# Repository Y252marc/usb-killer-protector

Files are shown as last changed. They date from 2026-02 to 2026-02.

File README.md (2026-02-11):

# USB killer Protector | 🛡️ USB SHIELD | The 5kV Hard-Isolation Barrier
**Magnetic isolation. Zero physical connection. Total motherboard safety.**





👉 **[Launch Interactive Project Site](https://y252marc.github.io/usb-killer-protector/)**

---

### ⚡ The Problem: The "Spark"
USB Killers don't hack your software; they execute your hardware. By dumping high-voltage DC into your port, they fry your motherboard in milliseconds. Standard protectors are too slow.

### 🔌 The Solution: The "Moat"
I didn't just build a filter; I built a physical gap. Data is teleported across a 4.5mm "moat" using magnetic fields, while power is handled by a floating transformer. If an attacker dumps 200V into the target side, it literally has no physical path to reach your laptop.

---

### 🛠️ Hardware Loadout
* **The Brain**: **ADuM4160** Digital Isolator (Rated for **5,000V** isolation).
* **The Power**: **RFM-0505S** Isolated DC-DC Converter (Floating 5V power).
* **The Guard**: Dual **SMAJ5.0A** TVS Diodes (Clamping transients at the source).
* **The Kill Switch**: **JS202011SCQN** DPDT switch for instant manual data disconnection.

---

### 📐 Engineering Excellence
* **Split Ground Planes**: Two entirely separate copper islands—Clean vs. Dirty.
* **Differential Data Highway**: Matched D+/D- lines with 24Ω termination for zero-drop communication.
* **Pro Layout**: 2-layer FR4 with 2mm rounded edges for a clean, crack-proof finish.

### 📂 Inside the Repo
* **3D Assets**: STEP models for the isolator, transformer, and ports.
* **Production**: Factory-ready Gerber and Drill files.
* **Source**: Full KiCad 9 design project.

---

### 📜 License
This project is licensed under the **MIT License** - see the [LICENSE](LICENSE) file for details.

### ⚠️ Disclaimer
*Testing destructive hardware is dangerous. This shield is for research and educational vibes only. Use it at your own risk.*

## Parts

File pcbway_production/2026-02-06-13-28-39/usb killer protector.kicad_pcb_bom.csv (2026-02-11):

Designator | Quantity | Value | Footprint | Package | MPN | DNP | Mount_Type | Description | MF | Description_1 | Price | SnapEDA_Link | MP | Availability | Check_prices | MFR_NAME | MANUFACTURER_PART_NUMBER | MAXIMUM_PACKAGE_HEIGHT | STANDARD | PARTREV | MANUFACTURER | SNAPEDA_PN | OC_FARNELL | SUPPLIER | OC_NEWARK
C1, C2, C3, C4 | 4 | 100uF | C_0805_2012Metric |  |  |  | smt | SMD 0805 MLCC capacitor, Alternate KiCad Library
C5 | 1 | 10uF | C_1206_3216Metric |  |  |  | smt | SMD 1206 MLCC capacitor, Alternate KiCad Library
D1, D2 | 2 | SMAJ5.0A | D_SMA |  |  |  | smt | SMA Unidirectional TVS diode, 5V, 400W, Alternate KiCAD Library
F1 | 1 | 0ZCJ0050FF2G | RESC3216X125N | 1206 Bel Fuse |  |  | smt |  | Bel Fuse | 1206 SMT PPTC | 0.50 Ih | 8V | None | https://www.snapeda.com/parts/0ZCJ0050FF2G/Bel+Circuit+Protection/view-part/?ref=snap | 0ZCJ0050FF2G | In Stock | https://www.snapeda.com/parts/0ZCJ0050FF2G/Bel+Circuit+Protection/view-part/?ref=eda
J1 | 1 | 480370001 | USB_A_Molex_48037-2200_Horizontal | None |  |  | smt |  | Molex | USB-A (USB TYPE-A) USB 2.0 Plug Connector 4 Position Through Hole, Right Angle | None | https://www.snapeda.com/parts/480370001/Molex/view-part/?ref=snap | 480370001 | In Stock | https://www.snapeda.com/parts/480370001/Molex/view-part/?ref=eda | Molex Connector Corporation | 480370001
J2 | 1 | USB1125-GF-B_REVA | GCT_USB1125-GF-B_REVA | None |  |  | tht |  | Global Connector Technology | USB 2.0 Receptacle, Type A, Through Hole, Horizontal, Top Mount, Without Flange, 6.48mm profile, 4 Pins, Through hole, compact receptacle, 5000 mating cycle, full size | None | https://www.snapeda.com/parts/USB1125-GF-B/Global+Connector+Technology/view-part/?ref=snap | USB1125-GF-B | In Stock | https://www.snapeda.com/parts/USB1125-GF-B/Global+Connector+Technology/view-part/?ref=eda |  |  | 6.63mm | Manufacturer Recommendations | A | GCT
R1, R2, R3, R4 | 4 | 24Ω | R_0805_2012Metric |  |  |  | smt | SMD 0805 Chip Resistor, European Symbol, Alternate KiCad Library
SW1 | 1 | JS202011SCQN | SW_JS202011SCQN | None |  |  | smt |  | C&K | Slide Switch DPDT Surface Mount | None | https://www.snapeda.com/parts/JS202011SCQN/C%2526K/view-part/?ref=snap | JS202011SCQN | In Stock | https://www.snapeda.com/parts/JS202011SCQN/C%2526K/view-part/?ref=eda |  |  | 5.5 mm | Manufacturer Recommendations | 26 May 22 | C&K | JS202011SCQN
U1 | 1 | ADUM4160BRWZ | SOIC127P1032X265-16N | SOIC-16 | ADUM4160BRWZ |  | smt |  | Analog Devices | Full/Low Speed USB Digital Isolator | None | https://www.snapeda.com/parts/ADUM4160BRWZ/Analog+Devices/view-part/?ref=snap | ADUM4160BRWZ | In Stock | https://www.snapeda.com/parts/ADUM4160BRWZ/Analog+Devices/view-part/?ref=eda |  |  |  |  |  |  |  | 1858056 | Analog Devices | 24R8652
U2 | 1 | RFM-0505S | CONV_RFM-0505S | SIP-4 Recom Power |  |  | tht |  | Recom Power | DC-DC Converter, SIP4, 1kV unreg, Single Output, 1W, 5V Out, RFM Series | RECOM Power Inc. RFM-0505S | None | https://www.snapeda.com/parts/RFM-0505S/Recom+Power/view-part/?ref=snap | RFM-0505S | In Stock | https://www.snapeda.com/parts/RFM-0505S/Recom+Power/view-part/?ref=eda |  |  | 10mm | Manufacturer Recommendations | 0 | Recom

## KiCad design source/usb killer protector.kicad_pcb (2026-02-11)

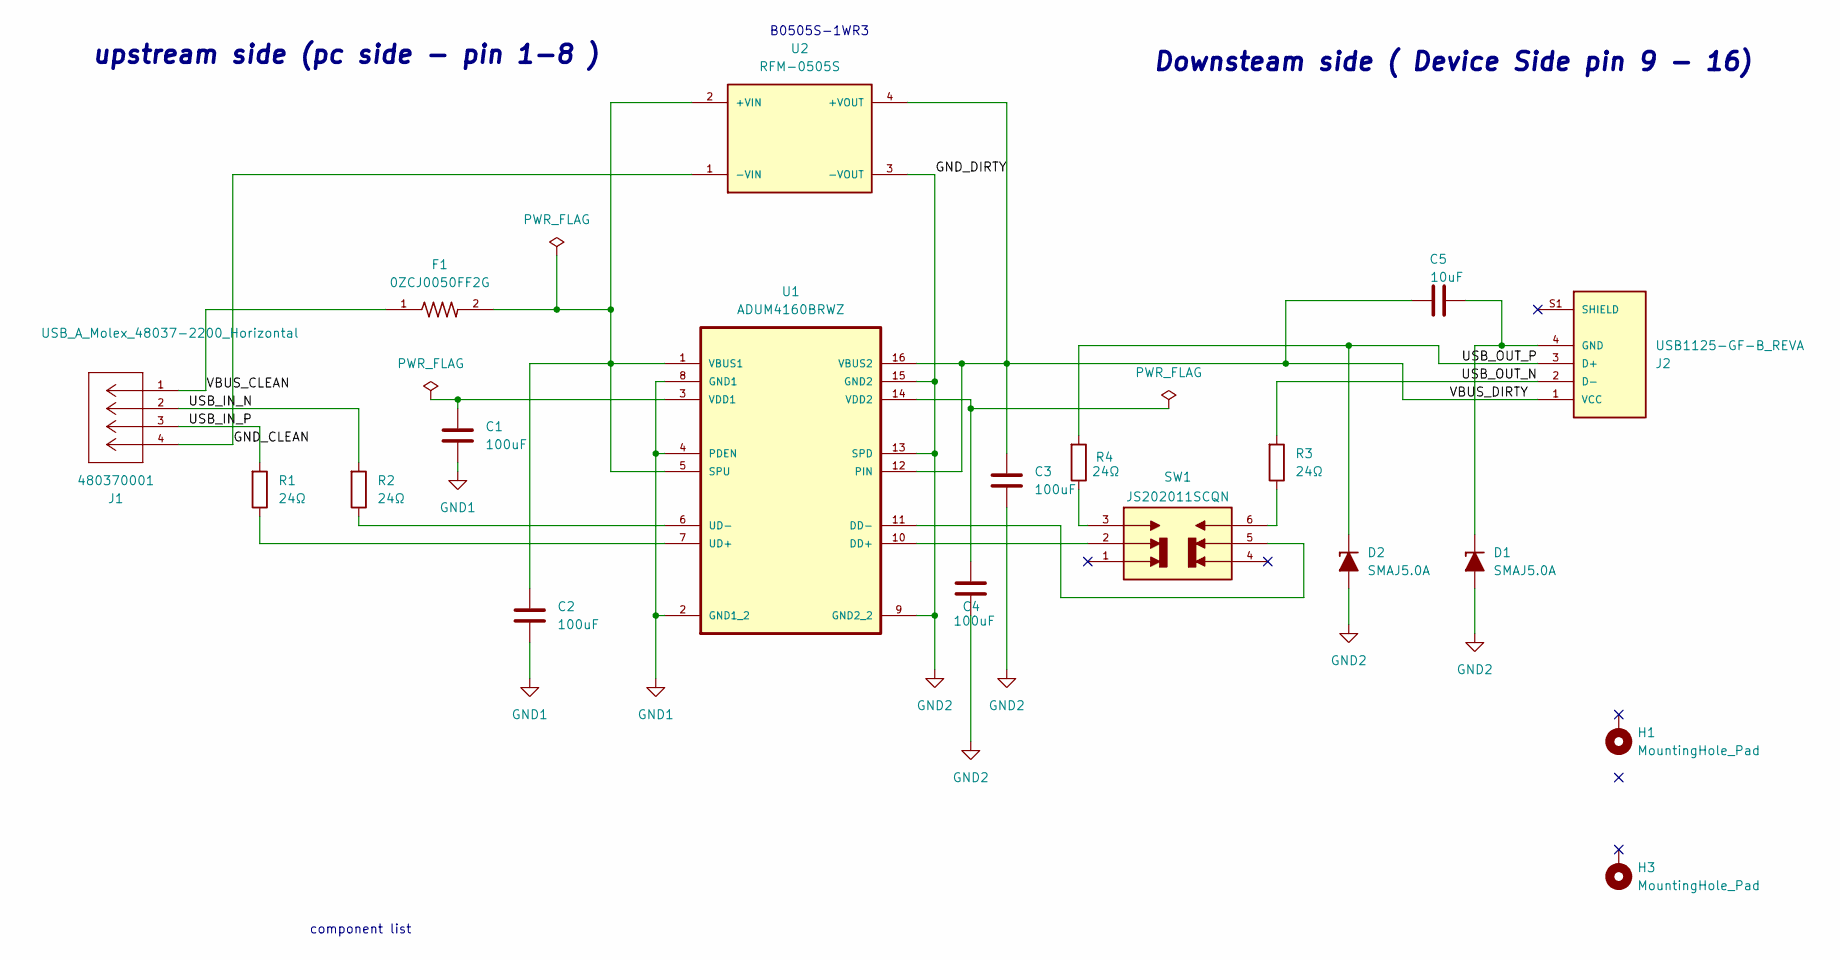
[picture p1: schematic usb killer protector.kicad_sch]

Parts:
C1, C2, C3, C4: 100uF; C_0805_2012Metric
C5: 10uF; C_1206_3216Metric
D1, D2: SMAJ5.0A; D_SMA
F1: 0ZCJ0050FF2G; RESC3216X125N
H1, H3: MountingHole_Pad; MountingHole_3.2mm_M3_Pad_Via
J1: 480370001; USB_A_Molex_48037-2200_Horizontal; MANUFACTURER_PART_NUMBER 480370001
J2: USB1125-GF-B_REVA; GCT_USB1125-GF-B_REVA; PARTREV A
R1, R2, R3, R4: 24Ω; R_0805_2012Metric
SW1: JS202011SCQN; SW_JS202011SCQN; PARTREV 26 May 22
U1: ADUM4160BRWZ; SOIC127P1032X265-16N; MPN ADUM4160BRWZ
U2: RFM-0505S; CONV_RFM-0505S; PARTREV 0

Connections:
/GND_CLEAN: J1.4, U2.1 (-VIN)
/USB_IN_N: J1.2, R2.1
/USB_IN_P: J1.3, R1.1
/USB_OUT_N: J2.2 (D-), R3.1
/USB_OUT_P: D2.1 (K), J2.3 (D+), R4.1
/VBUS_CLEAN: F1.1, J1.1
/VBUS_DIRTY: C3.1, C5.1, J2.1 (VCC), U1.12 (PIN), U1.16 (VBUS2), U2.4 (+VOUT)
GND1: C1.2, C2.2, U1.2 (GND1_2), U1.4 (PDEN), U1.8 (GND1)
GND2: C3.2, C4.2, D1.2 (A), D2.2 (A), U1.9 (GND2_2), U1.13 (SPD), U1.15 (GND2), U2.3 (-VOUT)
unnamed: C5.2, D1.1 (K), J2.4 (GND)
unnamed: R3.2, SW1.6
unnamed: R4.2, SW1.3
unnamed: SW1.2, U1.10 (DD+)
unnamed: SW1.5, U1.11 (DD-)
unnamed: C2.1, F1.2, U1.1 (VBUS1), U1.5 (SPU), U2.2 (+VIN)
unnamed: R1.2, U1.7 (UD+)
unnamed: R2.2, U1.6 (UD-)
unnamed: C1.1, U1.3 (VDD1)
unnamed: C4.1, U1.14 (VDD2)

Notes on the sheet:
B0505S-1WR3
Downsteam side ( Device Side pin 9 - 16)
component list
upstream side (pc side - pin 1-8 )

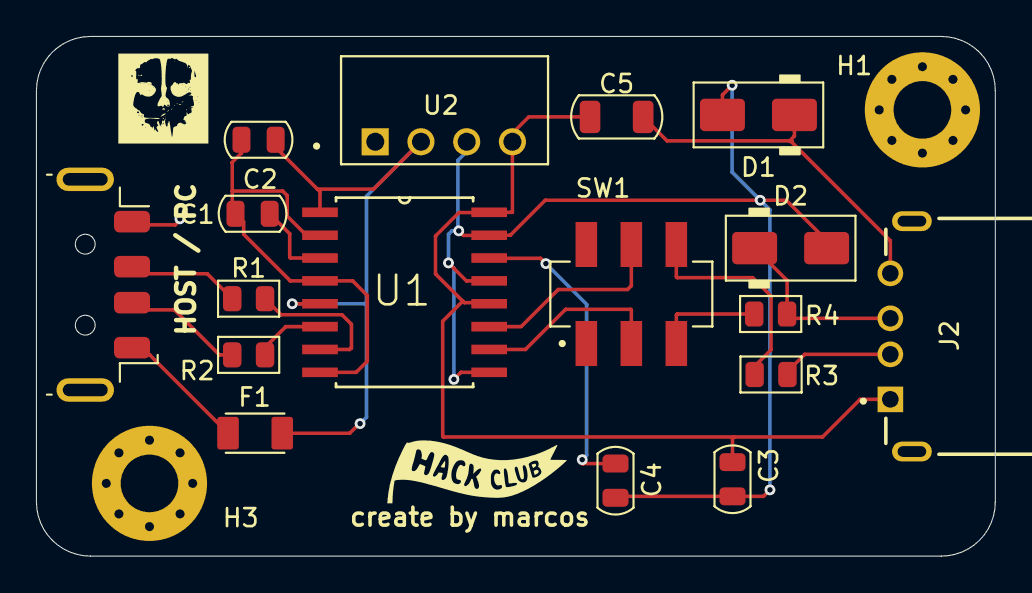
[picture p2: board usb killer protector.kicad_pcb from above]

Board: 2 copper layers, 53.3 x 28.9 mm, 19 parts (0 on the bottom side), 19 nets.

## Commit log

2026-02-11 initial release: pcb design and schematic complete
    [usb killer protector.csv, usb killer protector.kicad_pcb, usb killer protector.kicad_pcb_bom.csv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]
2026-02-11 bom file added
